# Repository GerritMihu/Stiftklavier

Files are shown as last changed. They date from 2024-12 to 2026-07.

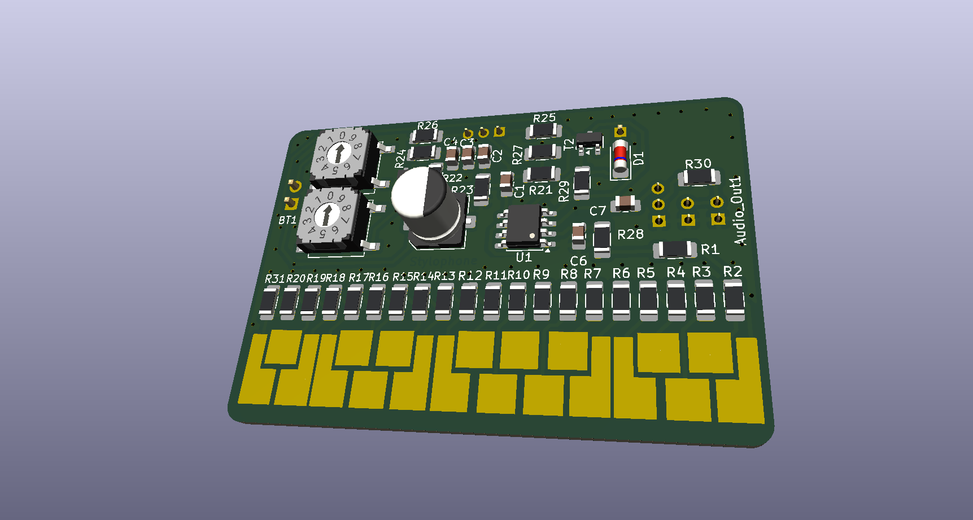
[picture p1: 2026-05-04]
bilder/Stiftklavier-render.png

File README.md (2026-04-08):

# Stiftklavier / Stylophone

**Ein Open-Source-Lehrprojekt für Mechatronik, Elektronik und Musik** – ideal für Workshops, Schulen und Maker.

Stiftklavier-Prototyp
*(Abb.: Fertiger Aufbau mit 3D-gedrucktem Gehäuse)*

---
## 🎯 Projektziel
Das Stiftklavier ist ein **praktisches Lehrmittel**, um:
✅ **Löten und Schaltungen** zu üben (Widerstände, ICs, Transistoren)
✅ **Grundlagen der Tonerzeugung** zu verstehen (Oszillatoren, Filter)
✅ **Mechatronik** zu verbinden (Elektronik + 3D-Druck + Mechanik)
✅ **Kreativität** zu fördern (individuelle Gehäuse, Sound-Experimente)

**Zielgruppe**: Student:innen, Lehrende, Elektronik-Enthusiast:innen

---
## 📦 Inhalte dieses Repos
| Ordner/Datei | Beschreibung |
|---|---|
| [`3D/`](3D/) | 3D-Modelle für Gehäuse (STL, FreeCAD) |
| [`bom/`](bom/) | Stücklisten (BOM) und Bestelllinks |
| [`cam/`](cam/) | **Automatisch generierte KiBot-Exporte** (PDF/PNG/3D) |
| [`Stylophone Documentation.md`](Stylophone%20Documentation.md) | **Detaillierte Aufbauanleitung** 🔗 |
| [`Stylophon_1.kicad_sch`](Stylophon_1.kicad_sch) | KiCad-Schaltplan und Platinenlayout |

---
## 🛠️ Loslegen
### 1. Material besorgen
- [Stückliste (BOM)](bom/) mit empfohlenen Händlern.
- **Werkzeuge**: Lötkolben, Multimeter, 3D-Drucker (optional).

### 2. Aufbauen
→ **[Schritt-für-Schritt-Anleitung](Stylophone%20Documentation.md)**

### 3. Erweitern
- Experimentiere mit **anderen Widerständen** für neue Tonleitern.
- Baue ein **MIDI-Interface** ein (Code-Beispiele folgen).

---
## 🔧 CI/CD mit KiBot (KiCad 10 Docker)
Dieses Repo nutzt **[KiBot](https://github.com/INTI-CMNB/KiBot)** in einem **vorkonfigurierten Docker-Container für KiCad 10**, um automatisch:
- **Schaltpläne als PDF** zu exportieren
- **Platinen-Layouts als PNG** zu rendern
- **3D-Ansichten** der Platine zu generieren

👉 **Ergebnisse**: Siehe [`cam/`](cam/)-Ordner (automatisch aktualisiert bei Pushs).

---
## 🤝 Mitwirken
- **Fehler gefunden?** → [Issue erstellen](https://github.com/GerritMihu/Stiftklavier/issues)
- **Verbesserungen?** → Pull Requests willkommen!
- **Fragen?** → Diskussionsbereich nutzen.

---
## 📄 Lizenz
[MIT](LICENSE) – Nutze, modifiziere und teile das Projekt frei!

<!-- KiBot Docker Pipeline Test Trigger: $(date +%s) -->

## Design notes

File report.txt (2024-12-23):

Warnung: Breitenkorrektur eingeschränkt.  Für die aktuellen Designregeln muss sich der Breitenkorrekturwert im Bereich [0,000001 mm; 0,199999 mm] befinden.
Fehler: Kann das Ausgabeverzeichnis "/cam" nicht erstellen.
Fehler: Kann das Ausgabeverzeichnis "/cam" nicht erstellen.

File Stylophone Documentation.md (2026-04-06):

# Stiftklavier – Aufbauanleitung

**Schritt-für-Schritt-Anleitung für den Aufbau des Stiftklaviers (Stylophone).**
🎯 **Ziel**: Ein funktionierendes, musikalisches Lehrmittel für Elektronik und Mechatronik.

---
## ⚠️ Wichtige Hinweise
> **Sicherheit & Qualität**
> - **IC-Orientierung prüfen**: Pin 1 ist mit einem Punkt markiert.
> - **Nur die großen Kupferflächen mit dem Stift berühren** – andere Bereiche können die Transistoren/ICs beschädigen.
> - **Lötstellen kontrollieren**: Keine Kurzschlüsse oder Kaltlötstellen!

---
## 📋 Material & Werkzeuge
### **Benötigte Komponenten** (siehe [BOM](bom/))
| Komponente | Menge | Hinweise |
|---|---|---|
| Widerstände | 12x | Werte nach Schaltplan (ggf. parallel/seriell kombinieren) |
| IC (z. B. 555-Timer)  | 1x | **Achtung**: Pin 1 markieren! |
| Potentiometer 1k/50k | 2x | 1k für Tonhöhe, 50k für Lautstärke |
| Lautsprecher | 1x | Polung beachten (siehe Schritt 3) |
| 9V-Blockbatterie | 1x | Frisch und voll geladen |
| Kabel (0,2 mm²) | 10x | 4x rot (120 mm), 6x schwarz (120 mm) |

### **Werkzeuge**
- Lötkolben + Lötzinn
- Multimeter (für Widerstandsprüfung)
- Seitenschneider + Abisolierzange
- 5,5 mm-Bohrer (für Potentiometer-Löcher)

---
## 🔧 Aufbau – Schritt für Schritt

### **1. Platine bestücken**
**Ziel**: Alle SMD-/Durchsteckkomponenten korrekt platzieren.
1. **Beginne mit den kleinsten Bauteilen** (Widerstände, Dioden, dann IC).
2. **Widerstände**:
   - Werte **exakt** nach Schaltplan wählen.
   - Falls nötig, Widerstände **parallel/seriell kombinieren** (z. B. 2x 10k → 5k).
3. **IC einlöten**:
   - **Pin 1** (markiert) **nach links oben** ausrichten.
   - **Prüfen**: Multimeter auf Durchgang – keine Kurzschlüsse zwischen Pins!

---
### **2. Kabel vorbereiten**
**Ziel**: 10 Kabel mit korrekter Länge und Abisolierung.
| Farbe  | Länge | Menge | Verwendung |
|---|---|---|---|
| Rot | 120mm | 4x | Stromversorgung/Buttons |
| Schwarz| 120mm | 6x | Masse/Potentiometer |
| Rot | 230mm | 1x | Lautsprecher (+) |
| Schwarz| 230mm | 2x | Lautsprecher (–)/Stylus |

**Schritte**:
1. Kabel auf Länge schneiden.
2. **10 mm abisolieren** (beidseitig).
3. **Lötzinn vorverzinnen** für bessere Verbindungen.

---
### **3. Lautsprecher anlöten**
**Ziel**: Stabile Verbindung für klare Tonwiedergabe.
1. **230 mm-Kabel** (rot/schwarz) an Lautsprecher löten.
   - **Polarität**: Rot = **+**, Schwarz = **–** (für gleiche Phasenlage bei mehreren Lautsprechern).
   - **Tipp**: Autolötpaste für bessere Haftung auf Metall verwenden.
2. **Prüfen**: Widerstandsmessung (sollte ~8 Ω sein).

---
### **4. Potentiometer vorbereiten**
**Ziel**: 1k- und 50k-Poti für Tonhöhe/Lautstärke einbauen.
1. **Schwarze Kabel** (120 mm) an **alle 3 Pins** jedes Potis löten.
2. **Positionieren**:
   - **1k-Poti**: Neben Lautsprecher (3 Löcher in Reihe).
   - **50k-Poti**: Andere Seite der Platine (3 Löcher).

---
### **5. Komponenten auf Platine löten**
**Ziel**: Alle vorbereiteten Teile (Lautsprecher, Potis, Batterieclip) anlöten.
- **Lautsprecher**: Auf der **Button-gegenüberliegenden Seite**.
- **Batterieclip**: Rot = **unten** (zu den Kupferflächen).
- **Stylus-Kabel**: 230 mm-Kabel an **einzelnes Loch nahe Diode** löten (anderes Ende später).

---
### **6. Erste Inbetriebnahme**
1. **Sichtprüfung**: Alle Lötstellen auf Kaltlötstellen/Kurzschlüsse prüfen.
2. **IC-Orientierung doppelt checken** (Pin 1!).
3. **9V-Batterie anschließen** – beide Buttons drücken → Ton sollte hörbar sein.

---
### **7. Gehäuse bearbeiten**
**Ziel**: 3D-gedrucktes Gehäuse für Potentiometer und Stylus anpassen.
1. **Bohrungen**:
   - **5,5 mm-Loch** für 1k-Poti **vergrößern** (existierendes Loch).
   - **Neues 5,5 mm-Loch** 20 mm rechts daneben bohren (für 50k-Poti).
   - **5 mm-Loch** für Stylus-Aufbewahrung (siehe [Abbildung 2](bilder/Abbildung2.png)).
2. **Potentiometer montieren**:
   - Von **innen** mit Heißkleber fixieren (nicht den Drehknopf verkleben!).
3. **Schraubmuttern einsetzen**:
   - **Heat-Set-Muttern** in die hinteren Löcher drücken und mit Lötkolben fixieren.

---
### **8. Platine einbauen**
1. Platine **horizontal von hinten** ins Gehäuse schieben (Kupferflächen nach vorne).
2. **9V-Batterie** unter der Platine platzieren.

---
### **9. Stylus vorbereiten**
**Ziel**: 100 mm-Kupferdraht (6 mm²) als Stift für die Tonabnahme.
1. **Ein Ende rund feilen**.
2. **15 mm abisolieren** und an das 230 mm-Kabel löten.
3. **Shrink-Tube** (40 mm) über die Lötstelle schieben und erhitzen.

---
### **10. Buttons anbringen**
- **Beide Buttons gleichzeitig drücken** → Ton erzeugt.
- **Deckel aufschrauben** (vorher Buttons durch die Löcher stecken).

---
## 🔍 Troubleshooting
| Problem | Ursache | Lösung |
|---|---|---|
| **Kein Ton** | Falsche IC-Orientierung | Pin 1 prüfen, ggf. umlöten |
| **Verzerrter Klang** | Kaltlötstelle am Lautsprecher | Nachlöten, Widerstand prüfen |
| **Buttons reagieren nicht** | Unterbrochene Kabel | Durchgang prüfen, neu löten |

---
## 📚 Weiterführendes
- [Schaltplan (PDF)](cam/Stylophon_1.pdf)
- [3D-Modelle für Gehäuse](3D/)
- [BOM mit Bestelllinks](bom/)

---
**Fertig!** 🎉
→ Experimentiere mit anderen Widerständen für neue Tonleitern oder baue ein MIDI-Interface ein.

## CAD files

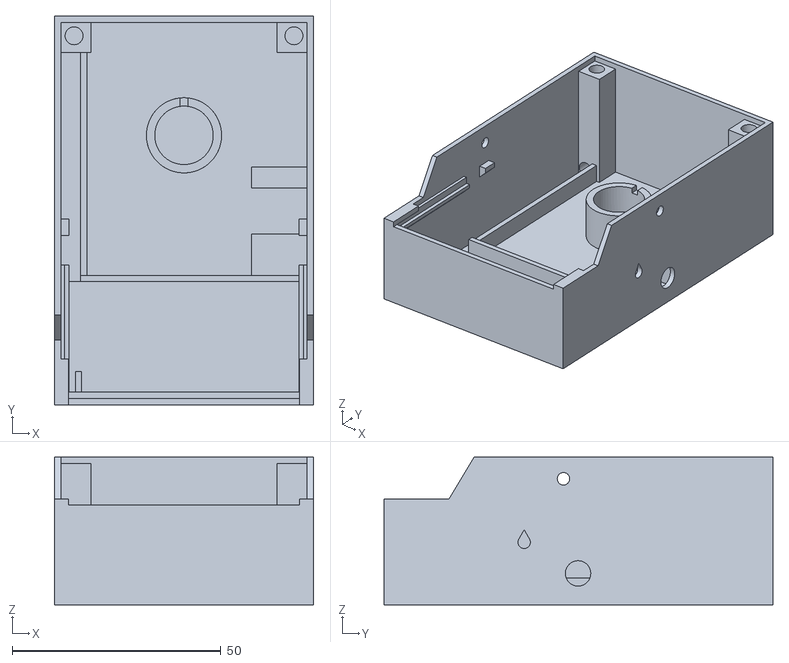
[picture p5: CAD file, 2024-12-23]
3D/stylofon-Schale.stl
62.0 x 93.0 x 35.4

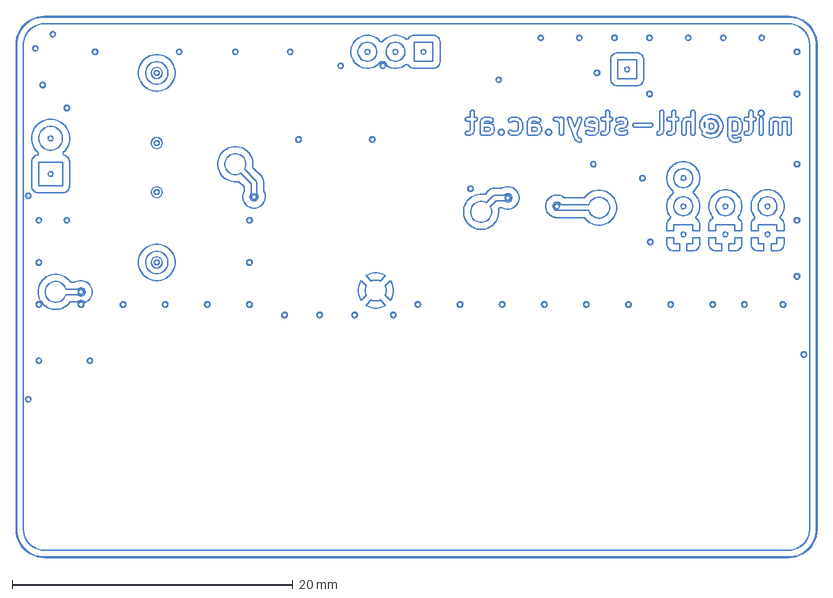
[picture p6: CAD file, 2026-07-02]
cam/Stiftklavier-B_Cu.dxf
57.0 x 38.5 mm

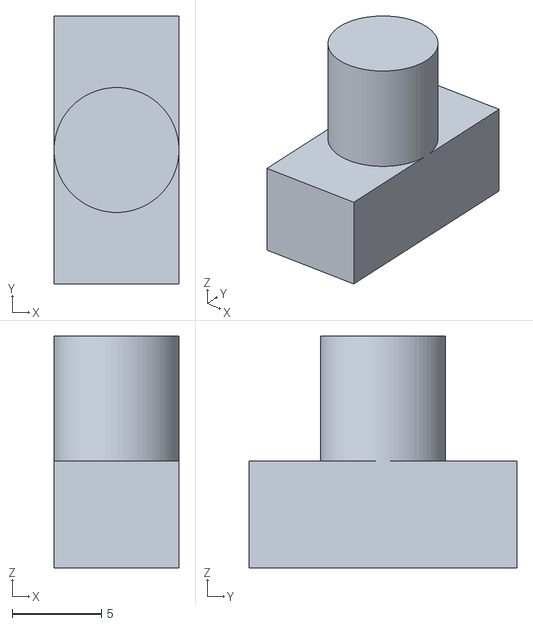
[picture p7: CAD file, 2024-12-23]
3D/stylofon-Knopf.stl
7.00 x 15.0 x 13.0

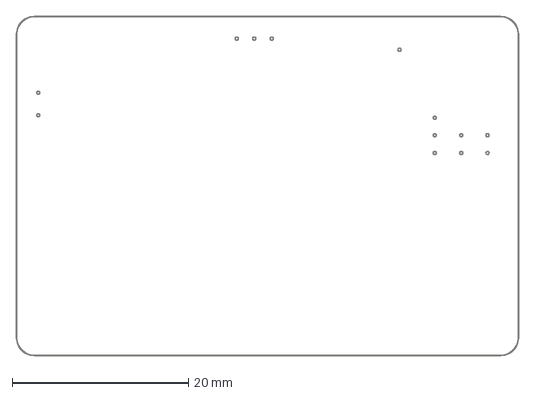
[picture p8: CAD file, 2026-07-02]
cam/Stiftklavier-Edge_Cuts.dxf
57.0 x 38.5 mm

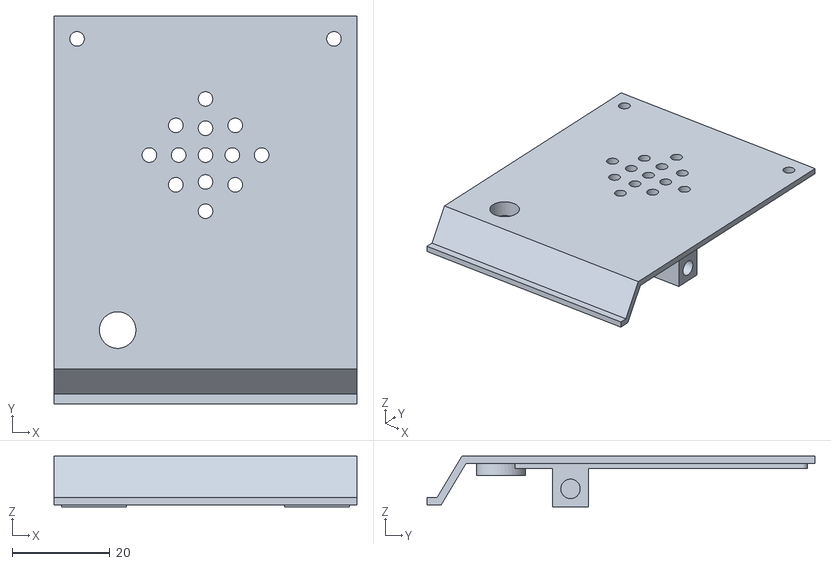
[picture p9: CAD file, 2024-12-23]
3D/stylofon-Deckel.stl
62.0 x 79.5 x 10.4

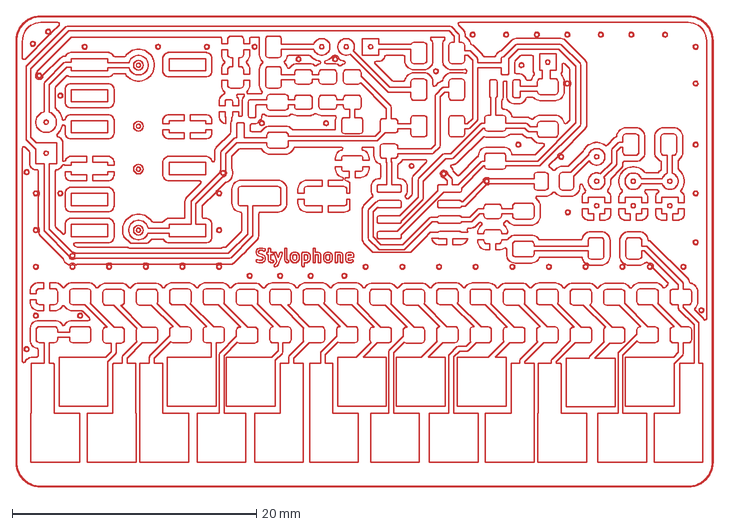
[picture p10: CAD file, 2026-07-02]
cam/Stiftklavier-F_Cu.dxf
57.0 x 38.5 mm

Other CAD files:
cam/Stiftklavier-B_Mask.dxf
cam/Stiftklavier-B_Paste.dxf
cam/Stiftklavier-B_Silkscreen.dxf
cam/Stiftklavier-F_Mask.dxf
cam/Stiftklavier-F_Paste.dxf
cam/Stiftklavier-F_Silkscreen.dxf

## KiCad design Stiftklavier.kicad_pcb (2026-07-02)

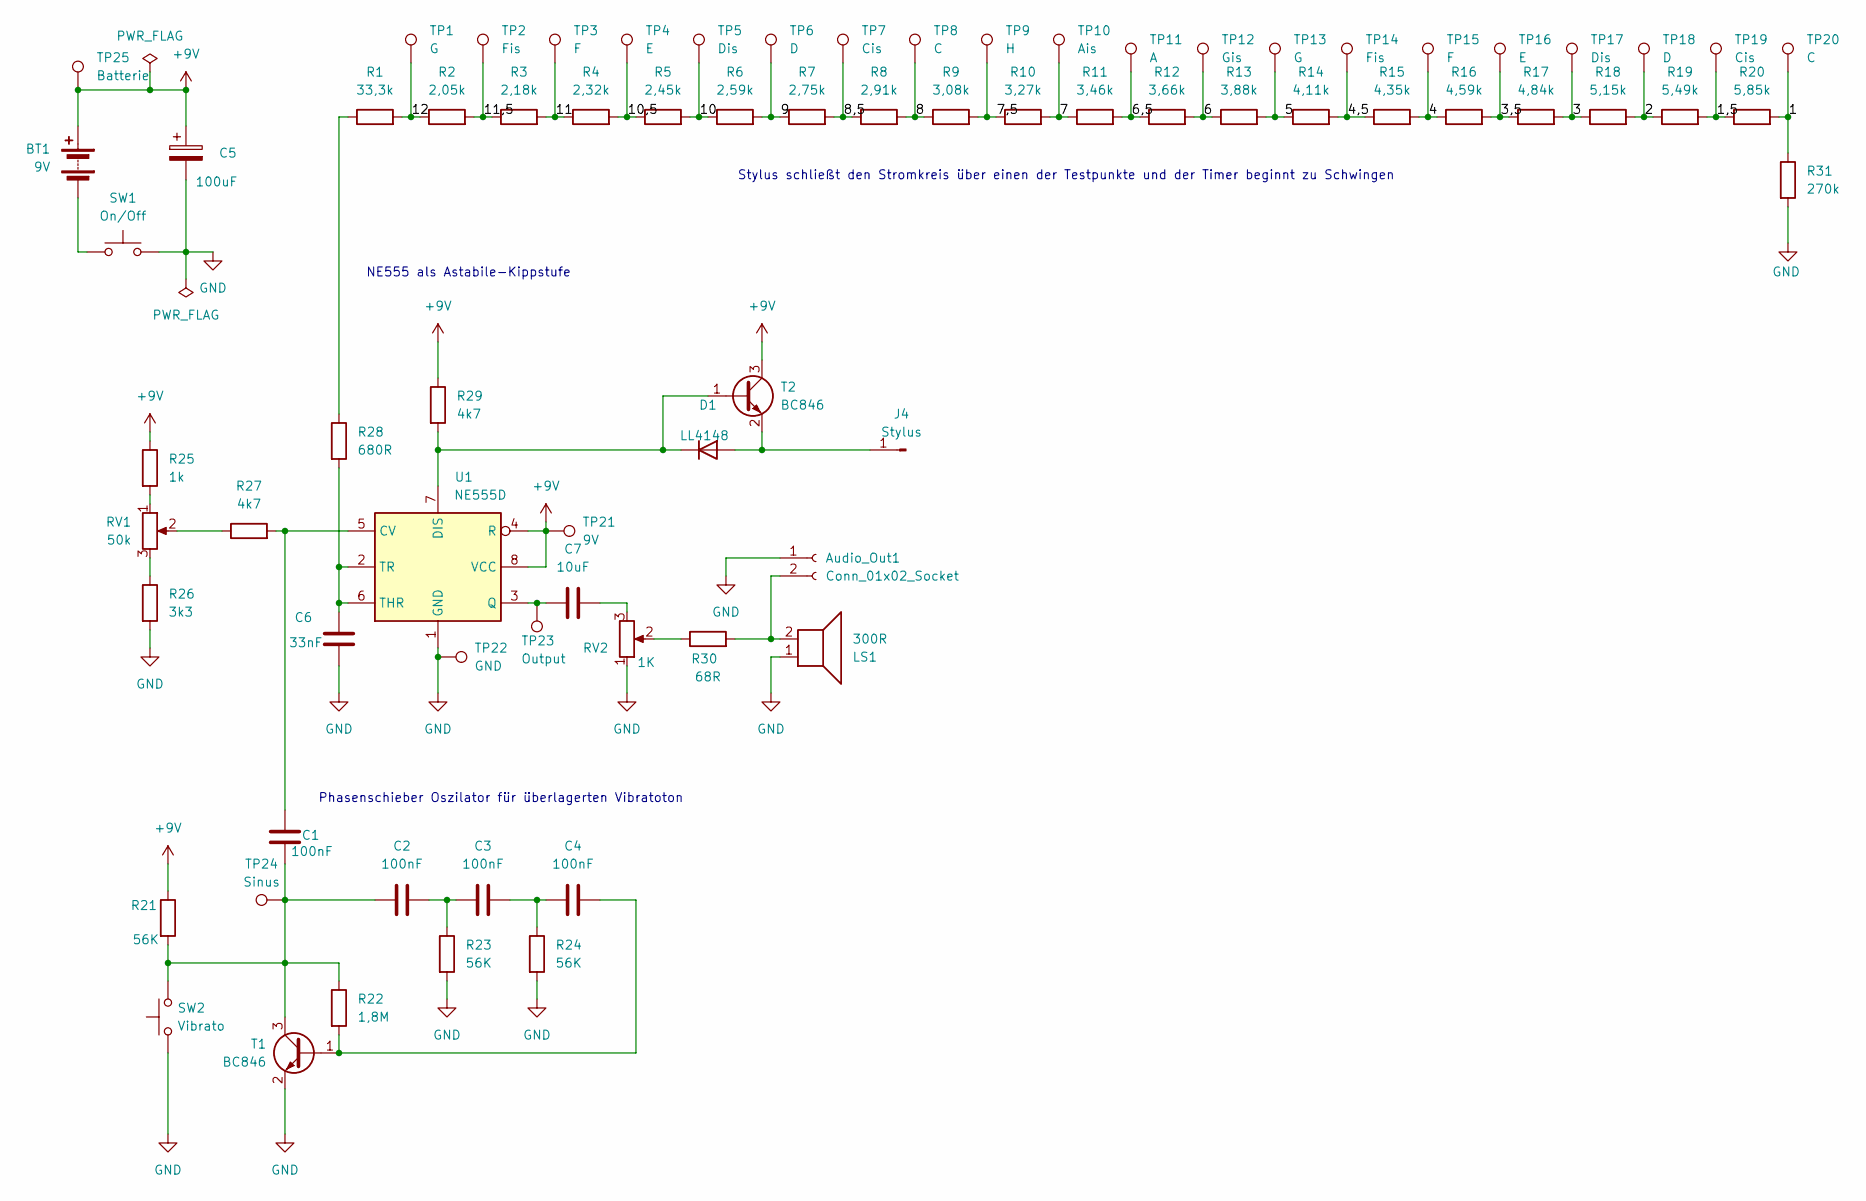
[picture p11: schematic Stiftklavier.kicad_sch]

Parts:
Audio_Out1: Conn_01x02_Socket; PinSocket_1x02_P2.00mm_Vertical
BT1: 9V; PinHeader_1x02_P2.54mm_Vertical
C1, C2, C3, C4: 100nF; C_0805_2012Metric_Pad1.18x1.45mm_HandSolder
C5: 100uF; CP_Elec_6.3x7.7
C6: 33nF; C_0805_2012Metric_Pad1.18x1.45mm_HandSolder
C7: 10uF; C_0805_2012Metric_Pad1.18x1.45mm_HandSolder
D1: LL4148; D_MiniMELF
J4: Stylus; PinHeader_1x01_P2.00mm_Vertical
LS1: 300R; PinSocket_1x02_P2.00mm_Vertical
R1: 33,3k; R_1206_3216Metric_Pad1.30x1.75mm_HandSolder
R2: 2,05k; R_1206_3216Metric_Pad1.30x1.75mm_HandSolder
R3: 2,18k; R_1206_3216Metric_Pad1.30x1.75mm_HandSolder
R4: 2,32k; R_1206_3216Metric_Pad1.30x1.75mm_HandSolder
R5: 2,45k; R_1206_3216Metric_Pad1.30x1.75mm_HandSolder
R6: 2,59k; R_1206_3216Metric_Pad1.30x1.75mm_HandSolder
R7: 2,75k; R_1206_3216Metric_Pad1.30x1.75mm_HandSolder
R8: 2,91k; R_1206_3216Metric_Pad1.30x1.75mm_HandSolder
R9: 3,08k; R_1206_3216Metric_Pad1.30x1.75mm_HandSolder
R10: 3,27k; R_1206_3216Metric_Pad1.30x1.75mm_HandSolder
R11: 3,46k; R_1206_3216Metric_Pad1.30x1.75mm_HandSolder
R12: 3,66k; R_1206_3216Metric_Pad1.30x1.75mm_HandSolder
R13: 3,88k; R_1206_3216Metric_Pad1.30x1.75mm_HandSolder
R14: 4,11k; R_1206_3216Metric_Pad1.30x1.75mm_HandSolder
R15: 4,35k; R_1206_3216Metric_Pad1.30x1.75mm_HandSolder
R16: 4,59k; R_1206_3216Metric_Pad1.30x1.75mm_HandSolder
R17: 4,84k; R_1206_3216Metric_Pad1.30x1.75mm_HandSolder
R18: 5,15k; R_1206_3216Metric_Pad1.30x1.75mm_HandSolder
R19: 5,49k; R_1206_3216Metric_Pad1.30x1.75mm_HandSolder
R20: 5,85k; R_1206_3216Metric_Pad1.30x1.75mm_HandSolder
R21, R23, R24: 56K; R_1206_3216Metric_Pad1.30x1.75mm_HandSolder
R22: 1,8M; R_1206_3216Metric_Pad1.30x1.75mm_HandSolder
R25: 1k; R_1206_3216Metric_Pad1.30x1.75mm_HandSolder
R26: 3k3; R_1206_3216Metric_Pad1.30x1.75mm_HandSolder
R27, R29: 4k7; R_1206_3216Metric_Pad1.30x1.75mm_HandSolder
R28: 680R; R_1206_3216Metric_Pad1.30x1.75mm_HandSolder
R30: 68R; R_1206_3216Metric_Pad1.30x1.75mm_HandSolder
R31: 270k; R_1206_3216Metric_Pad1.30x1.75mm_HandSolder
RV1: 50k; PinSocket_1x03_P2.00mm_Vertical
RV2: 1K; PinSocket_1x03_P2.00mm_Vertical
SW1: On/Off; Nidec_Copal_SH-7040B
SW2: Vibrato; Nidec_Copal_SH-7040B
T1, T2: BC846; SOT-23
TP1, TP13: G; Keypad_Right
TP2, TP14: Fis; Keypad_Small
TP3, TP15: F; Keypad_Small
TP4, TP16: E; Keypad_Small
TP5, TP17: Dis; Keypad_Left
TP6, TP18: D; Keypad_Right
TP7, TP19: Cis; Keypad_Small
TP8: C; Keypad_Small
TP9: H; Keypad_Small
TP10: Ais; Keypad_Small
TP11: A; Keypad_Small
TP12: Gis; Keypad_Left
TP20: C; Keypad_Left
TP21: 9V; TestPoint_Pad_D1.5mm
TP22: GND; TestPoint_Pad_D1.5mm
TP23: Output; TestPoint_Pad_D1.5mm
TP24: Sinus; TestPoint_Pad_D1.5mm
TP25: Batterie; TestPoint_Pad_D1.5mm
U1: NE555D; SOIC-8_3.9x4.9mm_P1.27mm

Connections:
+9V: BT1.1 (+), C5.1, R21.1, R25.1, R29.1, T2.3 (C), TP21.1, TP25.1, U1.4 (R), U1.8 (VCC)
/1: R20.2, R31.1, TP20.1
/1,5: R19.2, R20.1, TP19.1
/2: R18.2, R19.1, TP18.1
/3: R17.2, R18.1, TP17.1
/3,5: R16.2, R17.1, TP16.1
/4: R15.2, R16.1, TP15.1
/4,5: R14.2, R15.1, TP14.1
/5: R13.2, R14.1, TP13.1
/6: R12.2, R13.1, TP12.1
/6,5: R11.2, R12.1, TP11.1
/7: R10.2, R11.1, TP10.1
/7,5: R9.2, R10.1, TP9.1
/8: R8.2, R9.1, TP8.1
/8,5: R7.2, R8.1, TP7.1
/9: R6.2, R7.1, TP6.1
/10: R5.2, R6.1, TP5.1
/10,5: R4.2, R5.1, TP4.1
/11: R3.2, R4.1, TP3.1
/11,5: R2.2, R3.1, TP2.1
/12: R1.2, R2.1, TP1.1
GND: Audio_Out1.1, C5.2, C6.2, LS1.1, R23.2, R24.2, R26.2, R31.2, RV2.1, SW1.2, SW2.1, T1.2 (E), TP22.1, U1.1 (GND)
unnamed: Audio_Out1.2, LS1.2, R30.2
unnamed: BT1.2 (-), SW1.1
unnamed: C2.1, C3.2, R23.1
unnamed: C3.1, C4.2, R24.1
unnamed: C7.2, RV2.3
unnamed: D1.2 (A), J4.1, T2.2 (E)
unnamed: D1.1 (K), R29.2, T2.1 (B), U1.7 (DIS)
unnamed: R1.1, R28.1
unnamed: R25.2, RV1.1
unnamed: R26.1, RV1.3
unnamed: R27.1, RV1.2
unnamed: R30.1, RV2.2
unnamed: C4.1, R22.2, T1.1 (B)
unnamed: C1.1, C2.2, R21.2, R22.1, SW2.2, T1.3 (C), TP24.1
unnamed: C1.2, R27.2, U1.5 (CV)
unnamed: C7.1, TP23.1, U1.3 (Q)
unnamed: C6.1, R28.2, U1.2 (TR), U1.6 (THR)

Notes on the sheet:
Phasenschieber Oszilator für überlagerten Vibratoton
NE555 als Astabile-Kippstufe
Stylus schließt den Stromkreis über einen der Testpunkte und der Timer beginnt zu Schwingen

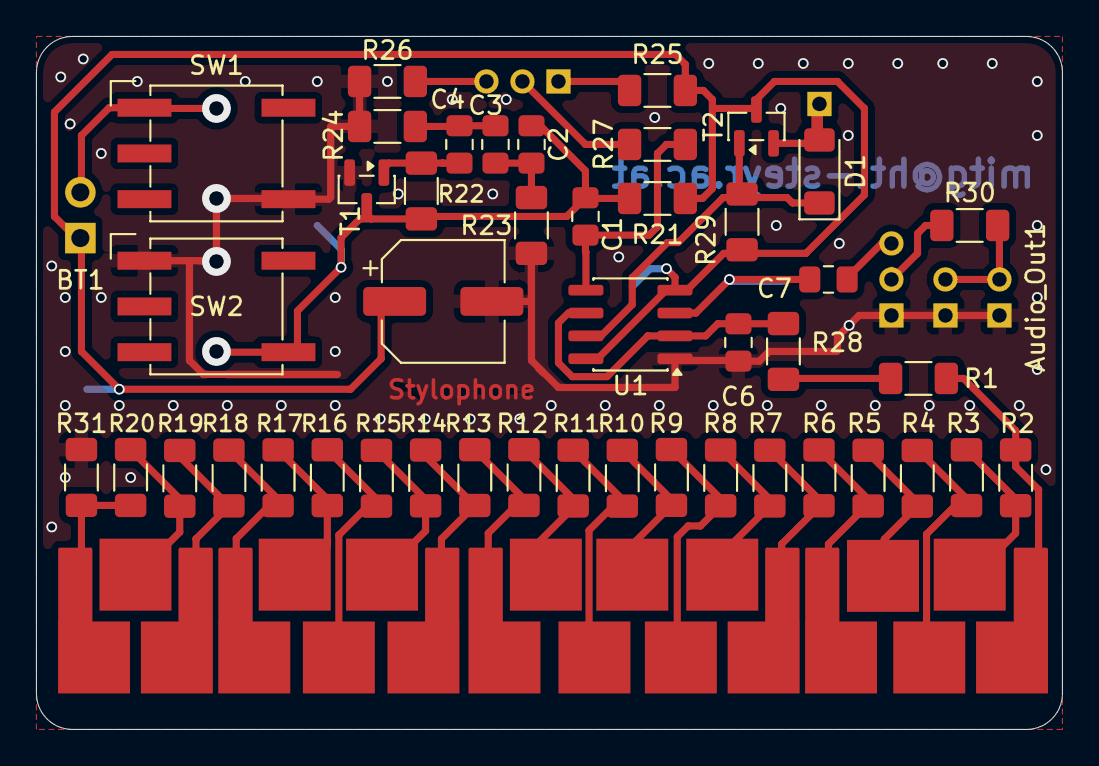
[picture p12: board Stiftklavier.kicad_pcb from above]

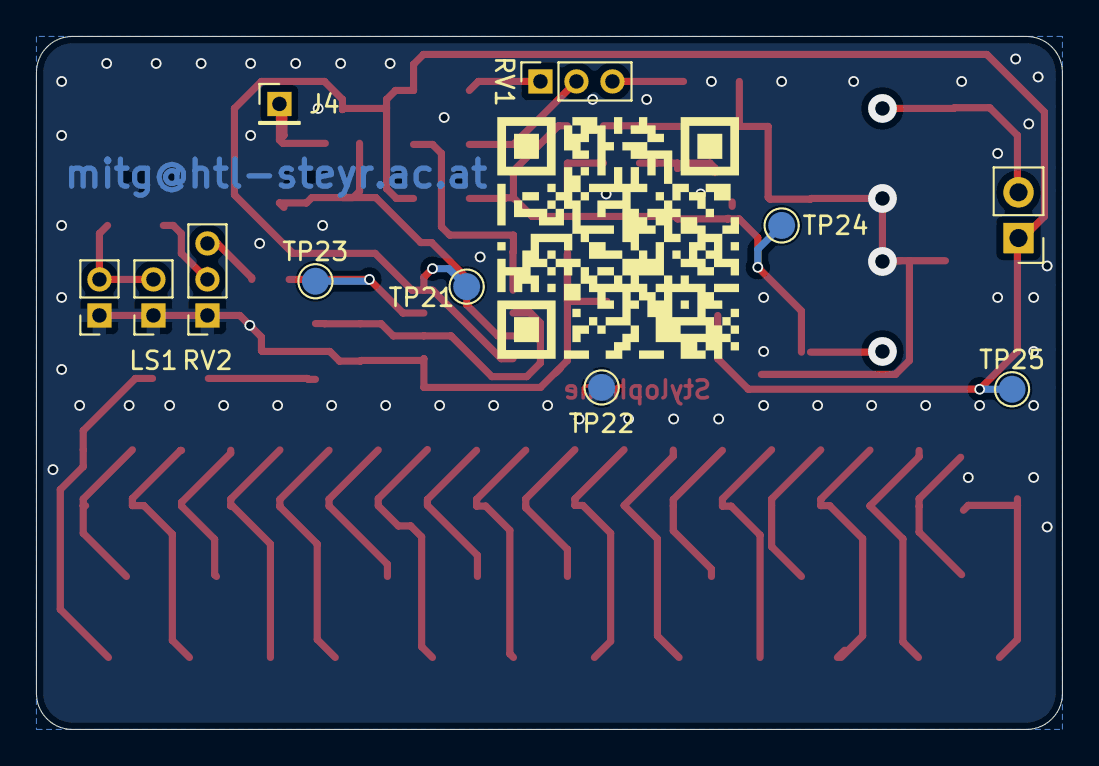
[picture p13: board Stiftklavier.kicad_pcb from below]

Board: 2 copper layers, 57.0 x 38.5 mm, 75 parts (11 on the bottom side), 39 nets.

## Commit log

2024-12-23 added directories for better organisation
    [Stylophon_1.kicad_pcb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]
2024-12-23 added case
    [stylofon-Deckel.stl, stylofon-Knopf.stl, stylofon-Schale.stl]
2025-09-07 Updated Component Values
    [Stylophon_1.kicad_sch]
2025-09-07 PCB updated
    [Stylophon_1.kicad_pcb, Stylophon_1.kicad_sch]
2025-09-07 Added keys like a real one
    [Stylophon_1.kicad_pcb, Stylophon_1.kicad_sch]
2025-09-07 VIA stitching & GND Plane QR
    [Stylophon_1.kicad_pcb, Stylophon_1.kicad_sch]
2026-03-23 Keyboard improvement
    [Stylophon_1.kicad_pcb]
2026-03-23 Release V1.0
    [Stylophon_1.kicad_pcb, Stylophon_1.kicad_sch]
2026-04-06 Add KiBot CI/CD workflow for automatic schematic/PCB exports
2026-04-06 Add KiBot configuration for schematic, PCB and 3D exports
2026-04-06 Update KiBot workflow for KiCad 10 compatibility
2026-04-06 Update KiBot config for KiCad 10 project file support
2026-04-06 Update README to reflect KiCad 10 and KiBot pipeline
2026-04-06 Fix KiBot installation with --no-compile for KiCad 10 compatibility
2026-04-08 Update to KiBot Docker container for KiCad 10
2026-05-04 Name correction
    [Stiftklavier.kicad_pcb, Stiftklavier.kicad_sch]
2026-05-04 Rename generate new gerber
    [Stiftklavier-B_Cu.gbr, Stiftklavier-B_Mask.gbr, Stiftklavier-B_Paste.gbr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]
2026-07-02 dxf created added xs file for xtool f2 ultra
    [Stiftklavier-B_Cu.dxf, Stiftklavier-B_Mask.dxf, Stiftklavier-B_Paste.dxf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]
